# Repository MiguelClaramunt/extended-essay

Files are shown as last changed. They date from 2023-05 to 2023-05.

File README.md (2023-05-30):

# USB-C Adapters: Design improvement using a 3D printer

### **Status: Work in progress**

HDMI | Ethernet | USB-A + SD
:---:|:--------:|:----------:
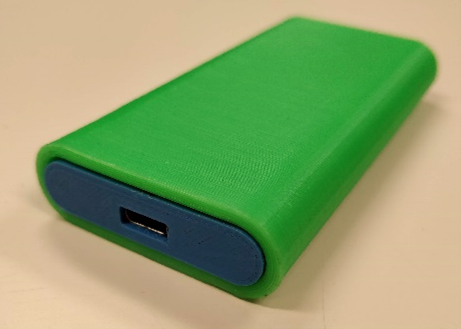
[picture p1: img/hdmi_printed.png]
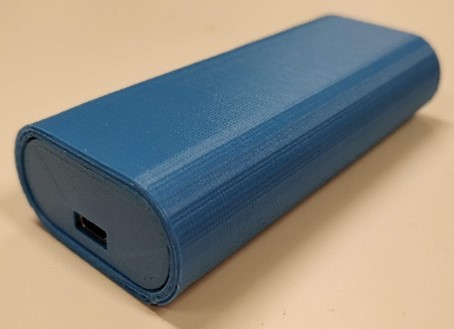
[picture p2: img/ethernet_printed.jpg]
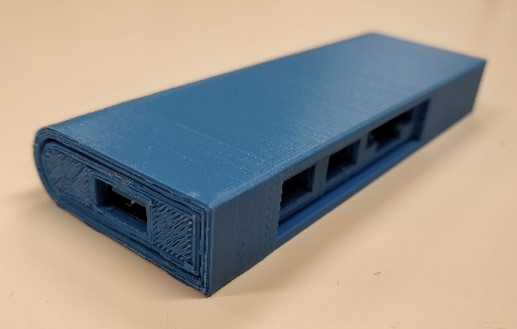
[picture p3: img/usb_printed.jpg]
 |  | 
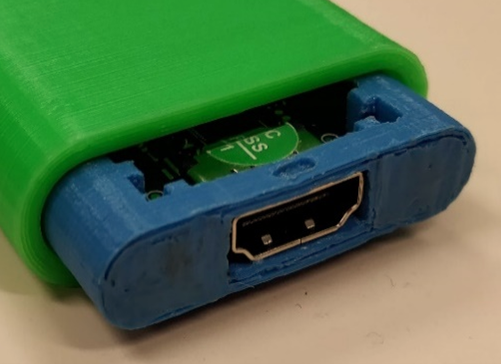
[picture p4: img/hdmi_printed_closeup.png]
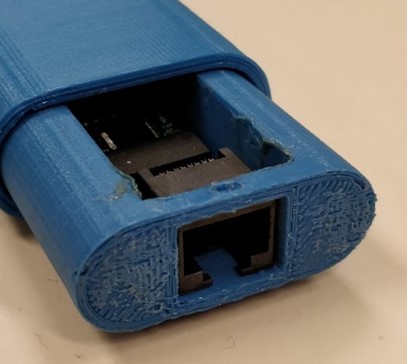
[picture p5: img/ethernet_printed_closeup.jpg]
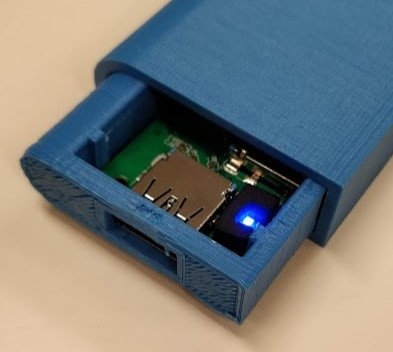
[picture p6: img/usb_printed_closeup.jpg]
 |  | 

## Research Question

> _"How can we improve the design of USB-C adapters to increase their durability and versatility?"_

<!-- ## Motivation -->

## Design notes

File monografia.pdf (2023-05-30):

# ADAPTADORES USB-C:

# MEJORA DEL DISEÑO UTILIZANDO

# UNA IMPRESORA 3D

## ¿Cómo podemos mejorar el diseño de los

## adaptadores de tipo USB-C para aumentar su

## durabilidad y versatilidad?

## Miguel Ricardo Claramunt Argote

Valencia, 21 de febrero de 2019

## Asignatura: TECNOLOGÍA DEL DISEÑO

Cómputo de palabras: 3949

## ÍNDICE

1. Introducción | 2
1.1 Introducción | 2
1.2 Pregunta de investigación | 3
1.3 Contexto | 4
1.4 Análisis de mercado | 6
1.5 Diseño | 7
1.6 Oportunidad de diseño | 9
1.7 Esquema general del proceso de producción | 11
2. Procedimiento | 11
2.1 Preparación del adaptador HDMI | 12
2.2 Preparación del adaptador Ethernet | 20
2.3 Preparación del adaptador USB/SD | 24
3. Conclusión | 28
4. Evaluación | 30
5. Bibliografía | 33

### 1. INTRODUCCIÓN (1467 palabras)

1.1.Introducción

El estándar USB-C es un nuevo tipo de

especificación de conexión que promete una

conexión físicamente reversible además de una

mayor tasa de transferencia de datos y potencia

de carga.

Con la implementación de este sistema, el

número de dispositivos que tienen este estándar ha aumentado considerablemente

desde su lanzamiento, con una previsión del 50% de smartphones y 93% de portátiles a

nivel mundial para el año 2020 (USB Implementers Forum, 2016). Aun así, para 2020

seguirá habiendo una gran lista de dispositivos con estándares anteriores (micro-USB,

VGA, etc.) por lo que la transición durará algunos años más.

En estos años de transición, existen situaciones en las que es necesario el uso de

adaptadores o dongles, como forma sustituir el estándar gradualmente. El problema que

hemos encontrado en su diseño es que suelen tener cables muy cortos y frágiles.

Además, el diseño de estos dispositivos, suele ser de una pieza, provocando que sean

irreparables, y con su uso diario haya que reemplazarlos en un corto período de tiempo.

Figura 1: Cable USB-C macho.

Fuente: Wikimedia Commons.

1.2.Pregunta de investigación

A partir de lo ya mencionado se nos ocurrió la siguiente pregunta de investigación:

“¿Cómo podemos mejorar el diseño de los adaptadores de tipo USB-C para aumentar

su durabilidad y versatilidad?”

Para responder esta pregunta diseñaremos un nuevo adaptador a partir de uno

ya comercializado, al que le diseñaremos una carcasa e intentaremos cambiar el tipo de

conexión que tiene (de USB-C macho a USB-C hembra) para hacerlo más duradero.

La carcasa la diseñaremos mediante el programa SketchUp y la imprimiremos con

una impresora 3D Prusa i3. Esta, mediante la extrusión de un filamento fundido por

capas, permite construir infinidad de modelos en cuestión de horas. El filamento que

utiliza, PLA (ácido poliláctico) es un polímero de origen orgánico, biodegradable y

reciclable, provocando que su impacto ambiental sea mínimo.

Gracias a que las impresoras 3D se han vuelto más populares y accesibles es

posible llevar a cabo proyectos como estos de forma sencilla, sin la necesidad de una

gran infraestructura.

Esta monografía se engloba dentro de la asignatura de Tecnología del Diseño, por

lo que nos centraremos en el diseño de las carcasas. Aun así, intentaremos abarcar un

poco del área de la electrónica, aunque no sea nuestro objetivo principal.

1.3.Contexto

El USB (USB-A) es un estándar cuyo diseño fue

publicado en 1996 con el fin de unificar la larga lista de

periféricos que había disponible, ofreciendo mayores

tasas de transferencia de datos, conexión en caliente

(sin tener que apagar el dispositivo), etc.

El nuevo estándar USB-C intenta solucionar los

problemas que tienen los demás estándares. Esto lo hace mediante la creación de un

puerto único, más pequeño (aproximadamente un 60% respecto al USB-A), mayores

tasas de carga y transferencia de datos. Además, su diseño permite que se pueda utilizar

de forma reversible, eliminando errores al conectarlo. Por lo tanto, se convierte en un

conector muy versátil, pudiendo colocarlo en la mayoría de aparatos electrónicos.

Para comenzar a mejorar el diseño de los adaptadores, escogimos diferentes

modelos para poner en práctica la versatilidad de este estándar, ya que puede transmitir

información a través de un gran número de protocolos: ethernet, video, audio, datos, etc.

De los protocolos mencionados anteriormente elegimos el de datos, vídeo y

ethernet. Realizamos una búsqueda en Amazon para comprar los modelos más afines a

este proyecto, que fueron los siguientes:

Figura 2: Cable USB-A macho.

Fuente: Wikimedia Commons.

Figura 3: Adaptador USB/SD

(AUKEY Hub USB 3.0, SD y

Micro SD)

Figura 4: Adaptador Ethernet

AUKEY.

Figura | 5: | Adaptador | HDMI

UGREEN.

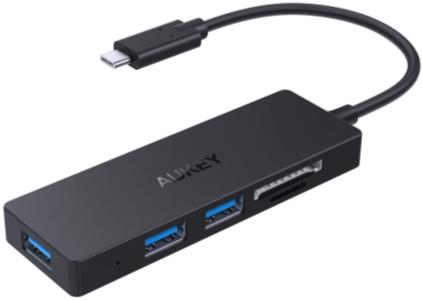
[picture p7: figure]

Fuente: Amazon. | Fuente: Amazon. | Fuente: Amazon.

Estos adaptadores constan de los siguientes componentes:

- Una placa base, que es la que se encarga de procesar la información proveniente

de un dispositivo principal (por ejemplo, la señal de vídeo de un ordenador) y

transmitirla al dispositivo secundario (un televisor).

- Un cable USB-C macho, que se conectaría al dispositivo principal, facilitando la

conexión entre ambos dispositivos (principal y secundario).

- Una carcasa, que contiene la placa base y sus circuitos internos, protegiéndola

del exterior.

Figura 6: Esquema de elementos de un adaptador.

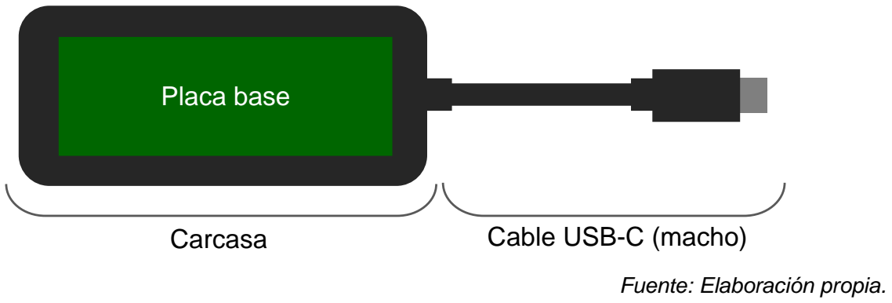
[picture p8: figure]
Fuente: Elaboración propia.; Carcasa; Cable USB-C (macho); Placa base

1.4.Análisis de mercado

Como hemos mencionado, el estándar USB-C es muy versátil, por lo que los

fabricantes se han aprovechado de ello para desarrollar una gran serie de productos que

se adapten a las necesidades de los compradores.

La mayoría de estos productos suelen conectarse directamente al USB-C del

dispositivo y mimetizarse con el diseño de este (véase Figura 7). Además, permiten una

gran serie de conexiones a una alta velocidad con el uso de un conector (véase Figura

8). Todos ellos intentan darle más esperanza de vida al estándar antes de que quede

obsoleto mientras los compradores pueden adaptarse paulatinamente a la

implementación completa del estándar.

Figura 7: Hub USB-C ENKLEN. | Figura 8: Hub USB-C 5 Lenovo.

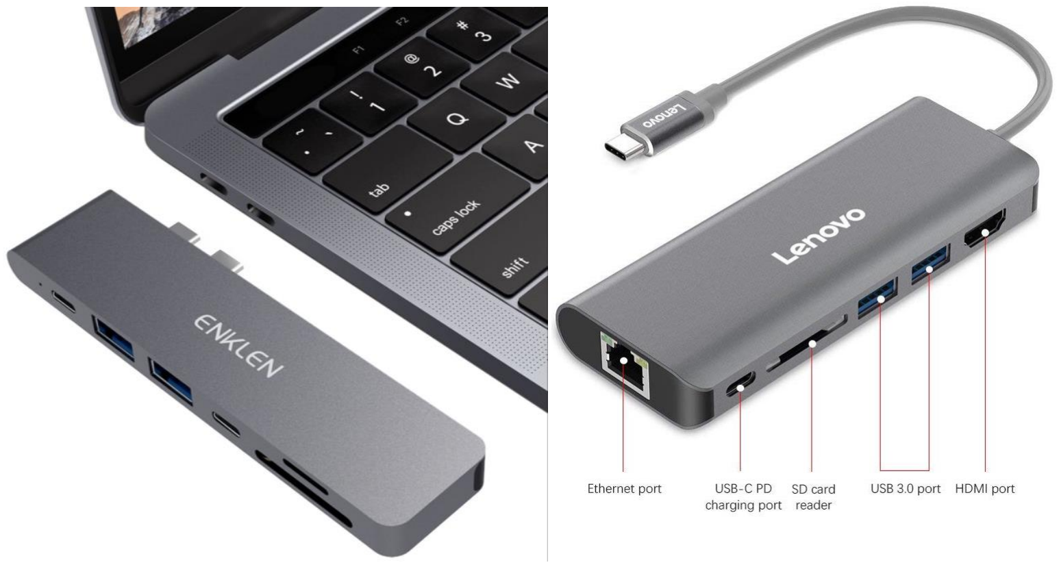
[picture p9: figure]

Fuente: Amazon. | Fuente: Amazon.

1.5.Diseño

Nos inspiramos en el diseño que tienen los

adaptadores de Apple, ya que su diseño es muy

similar en todos los tipos de adaptadores que tienen

en venta: un ortoedro con semicilindros en dos de sus

lados opuestos.

Nuestra propuesta de diseño es la siguiente: utilizar la placa base existente, a la

que retiraremos el cable USB-C macho y soldaremos una placa USB-C hembra,

finalmente, diseñaremos una carcasa que contendría a la placa base y al USB-C hembra.

El cambio de conector USB-C (macho por hembra) nos permite utilizar un cable

USB-C macho-macho. Así podríamos quitar el cable para que el adaptador ocupe

menos, reemplazarlo por uno nuevo si este se rompe por el uso o utilizar un cable con

una longitud diferente si la situación lo requiere.

Figura | 9: | Ortoedro | con | dos

semicilindros en sus lados opuestos.

Fuente: Elaboración propia.

Figura 10: Adaptador

USB-C a SD.

Figura 11: Adaptador

USB-C a USB-A.

Figura 12: Adaptador

USB-C a HDMI y USB-A.

Figura 13: Adaptador

USB-C a Ethernet.

Fuente: Apple. | Fuente: Apple. | Fuente: Apple. | Fuente: Apple.

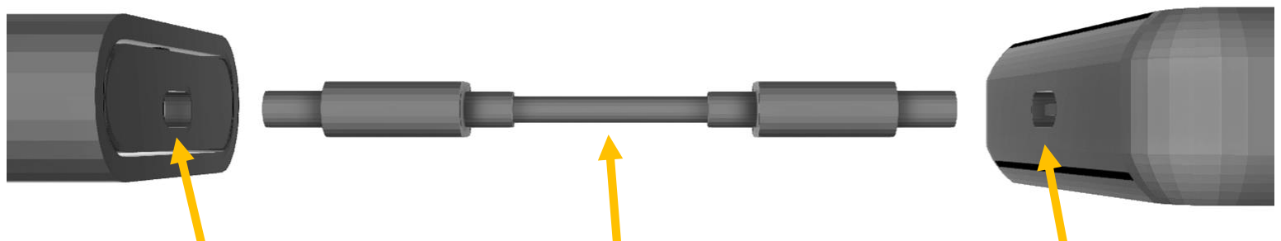
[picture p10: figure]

La carcasa consistiría en un cuerpo y una tapa, permitiendo proteger los

componentes internos de amenazas externas (golpes, caídas, etc.) aunque sin dificultar

el acceso a los mismos componentes. Por ende, el proceso de reparación o modificación

sería mucho más sencillo. El diseño de la carcasa sería idéntico al de la estructura

externa del cuerpo, pero eliminando las dos paredes que corresponden al lugar donde

están colocados el puerto del adaptador y el cable USB-C hembra. Así, para cerrar el

adaptador solamente habría que deslizar el cuerpo dentro de la tapa hasta alinearla con

el sistema de cierre.

El sistema de cierre entre la tapa y el cuerpo constaría de un saliente en el interior

de la tapa y un agujero en el cuerpo. Entonces, al deslizar el cuerpo dentro de la tapa, el

saliente y el agujero encajarán y las dos partes quedarían bloqueadas. Para expulsar el

cuerpo solamente haría falta hacer un poco de presión en él.

Figura 14: Funcionamiento de los adaptadores a partir del nuevo diseño.

Fuente: Elaboración propia.

Adaptador USB-C a
HDMI, Ethernet,
USB/SD, etc.
Cable USB-C macho-macho | Dispositivo principal (disco duro, ordenador, etc.)

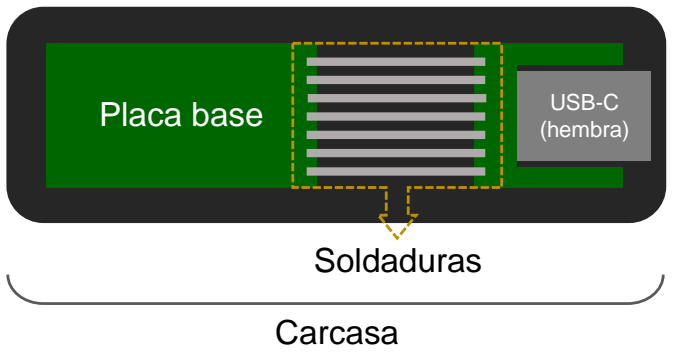
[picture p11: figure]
Placa base; USB-C; (hembra); Carcasa; Soldaduras

1.6.Oportunidad de diseño

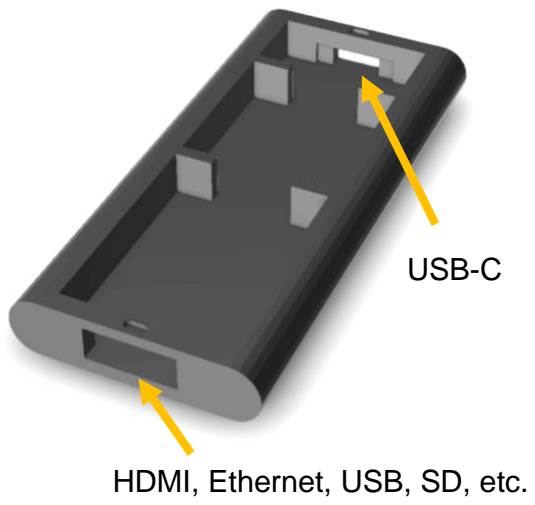
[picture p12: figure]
HDMI, Ethernet, USB, SD, etc.; USB-C

Mediante este cambio de diseño en la carcasa y componentes internos,

mejoraríamos la resistencia y la versatilidad del adaptador por las siguientes razones:

Resistencia:

- El cable, uno de los componentes más frágiles, se pordía reemplazar fácilmente,

evitando desmontarlo y soldarlo para sustituirlo.

Figura 15: Propuesta de diseño (cuerpo y circuitería). | Figura 16: Propuesta de diseño (tapa).
Fuente: Elaboración propia. | Fuente: Elaboración propia.
Figura 17: Propuesta de diseño (sistema de cierre). | Figura 18: Propuesta de diseño (cuerpo).

c

Fuente: Elaboración propia. | Fuente: Elaboración propia.
Agujero | Saliente

- La carcasa, al poder abrirse, permitiría reparar los componentes internos que se

hayan estropeado o incluso actualizarse si la tecnología evoluciona, alargando la

vida útil del adaptador considerablemente.

Versatilidad:

- Ocuparía menor espacio, ya que el módulo y el cable se podrían colocar por

separado.

- Se podrían conectar cables de diferentes longitudes según la situación,

permitiendo su uso en situaciones más diversas.

Otros factores que se mejorarían del diseño serían los siguientes:

- La sostenibilidad ambiental, mediante el uso de PLA (ácido poliláctico), un

polímero biodegradable y reciclable. Al ser de origen orgánico, su impacto

ambiental se reduce drásticamente.

- La personalización del diseño, pudiendo realizarse fácilmente mediante

herramientas de diseño en 3D permite que cada persona pueda adaptar la

carcasa a sus necesidades.

- Una mayor accesibilidad al público, que puede imprimir sus diseños de carcasas

mediante una impresora 3D, llegando hasta a países en vías de desarrollo, donde

la infraestructura tecnológica no permite tal tipo de proyectos.

1.7.Esquema general del proceso de producción

Los pasos que realizaremos en los tres adaptadores fueron los siguientes:

1. Preparación de la placa base.

1.1.Desensamblaje de la carcasa original.

1.2.Eliminación del puerto USB-C macho.

2. Preparación del conector USB-C hembra.

2.1.Diseño del esquema de conexiones.

2.2.Preparación y soldadura de los cables del adaptador al conector USB-C hembra.

3. Diseño e impresión de las carcasas.

3.1.Toma de medidas y diseño del prototipo.

3.2.Impresión del prototipo.

3.3.Diseño final.

3.4.Impresión del diseño final.

4. Comprobación y mejora de errores.

### 2. PROCEDIMIENTO (1561 palabras)

El procedimiento que vamos a utilizar en los tres adaptadores va a ser

prácticamente el mismo, por esta razón, comenzaremos con el adaptador más complejo,

describiendo con mucha precisión todos los pasos e inconvenientes del proceso.

Seguidamente, con los siguientes adaptadores explicaremos el procedimiento de

manera más resumida, aunque haciendo hincapié en los problemas encontrados,

evitando redundancias y haciendo más amena la lectura.

2.1.Preparación del adaptador HDMI.

1. Preparación de la placa base.

1.1.Desensamblaje de la carcasa original.

La primera parte del proceso de preparación del adaptador HDMI consistió en

retirar la placa base de la carcasa original (véase Figura 5).

Al tratarse de una carcasa de aluminio, para retirarla tuvimos que limarla hasta

llegar a la placa. Este paso hay que hacerlo con precaución, ya que las limaduras

metálicas pueden causar algún tipo de cortocircuito o fallo de la placa. En el proceso

de doblar la carcasa para extraer la placa hay que tener cierto cuidado para no

golpear y despegar ningún chip soldado a la placa base. La carcasa, al tener poca

superficie, ser muy dura y tener poco espacio de maniobra provocó que aplicáramos

mucha fuerza en ella, resultando que golpeáramos con un alicate un chip y

dejáramos la placa inutilizable, por lo que tuvimos que sustituirla. Por esa razón,

decidimos elegir un modelo diferente, este en vez de tener una salida HDMI macho

decidimos que fuera hembra. De esta forma se adaptaría más a nuestra lista de

características que queremos mejorar.

A la hora de retirar la carcasa el proceso fue más sencillo debido a que la

forma era diferente y el material era más dúctil, por lo que no hubo ninguna

complicación.

1.2.Eliminación del puerto USB-C macho.

Para este proceso cogimos el cable USB-C macho, lo cortamos con unas

tijeras, retiramos el apantallado metálico y plástico con unas tijeras. De esta forma

teníamos todos los cables disponibles para soldarlos.

2. Preparación del conector USB-C hembra.

2.1.Diseño del esquema de conexiones.

Para realizar el esquema de las conexiones utilizamos el cable USB-C macho

cortado anteriormente, pelamos los cables y conectamos el cable a la placa USB-C

hembra. De esta forma, con la ayuda de un multímetro podemos asignar un cable

con una pista de la placa.

Figura 19: Placa USB-C hembra con esquema de pistas. | Figura 20: Esquema de pistas y cables.

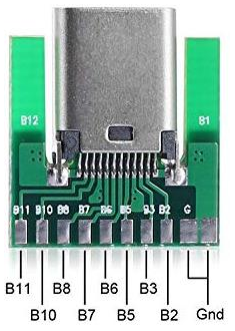
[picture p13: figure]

Pista | Cable | Pista | Cable
Gnd | Negro-Rojo | Gnd | Negro-Rojo
B2 | Azul | A2 | Marrón
B3 | Amarrillo | A3 | Blanco
B5 | Azul | Vcc | -
B6 | Verde | A5 | Amarillo
B7 | Blanco | A6 | -
B8 | Morado | A7 | -
B10 | Blanco | A8 | Rosa
B11 | Rojo | A10 | Naranja
| | A11 | Morado

Cada par de pistas coloreadas representa dos cables trenzados.

Fuente: Amazon. | Fuente: Elaboración propia.

2.2.Preparación y soldadura de los cables del adaptador al conector USB-C

hembra.

Una vez preparados los cables y retirado el apantallado procedimos a pelarlos,

de esta forma podíamos soldarlos adecuadamente. A continuación, decapamos y

estañamos los cables.

Hay que tener especial cuidado al pelar los cables, ya que estos son muy finos

y se rompen fácilmente con el uso de herramientas como un pelacables. Por esta

razón, los retiramos con mucho cuidado y la ayuda de una cuchilla o con las uñas

para retirar el aislante.

Con los cables ya estañados y el esquema de las conexiones listo, procedimos

a soldar cada cable en su conexión. Para ello utilizamos un soldador de punta fina,

estaño y decapante.

3. Diseño de la carcasa.

3.1.Toma de medidas y diseño del prototipo.

Con un pie de rey realizamos las medidas pertinentes de la placa base y las

apuntamos para pasarlas al programa de diseño 3D. Procedimos a diseñar un

prototipo “base”, en el que probaremos la estructura de la carcasa y a partir de ahí

iremos añadiendo mejoras estéticas.

Con el programa SketchUp dibujamos la plantilla del espacio que ocuparía la

placa base y a partir de ahí diseñamos una carcasa sin ningún tipo de decoración

estética para comprobar su estructura y si los espacios para los puertos estaban bien

colocados.

3.2.Impresión del prototipo.

Después de haber diseñado el prototipo procedimos a imprimirlo con la

impresora 3D, para ello exportamos el diseño de SketchUp en formato stl. No

encontramos ningún problema significativo, por lo que continuamos con el diseño del

prototipo final.

3.3.Diseño final.

A partir del diseño del prototipo “base” que imprimimos anteriormente,

procedimos a añadir las características mencionadas en el diseño final. Para ello,

añadimos las dos caras curvas y ajustamos la altura para que fuese simétrico.

Finalmente, diseñamos la tapa y añadimos el sistema de cierre en las dos partes.

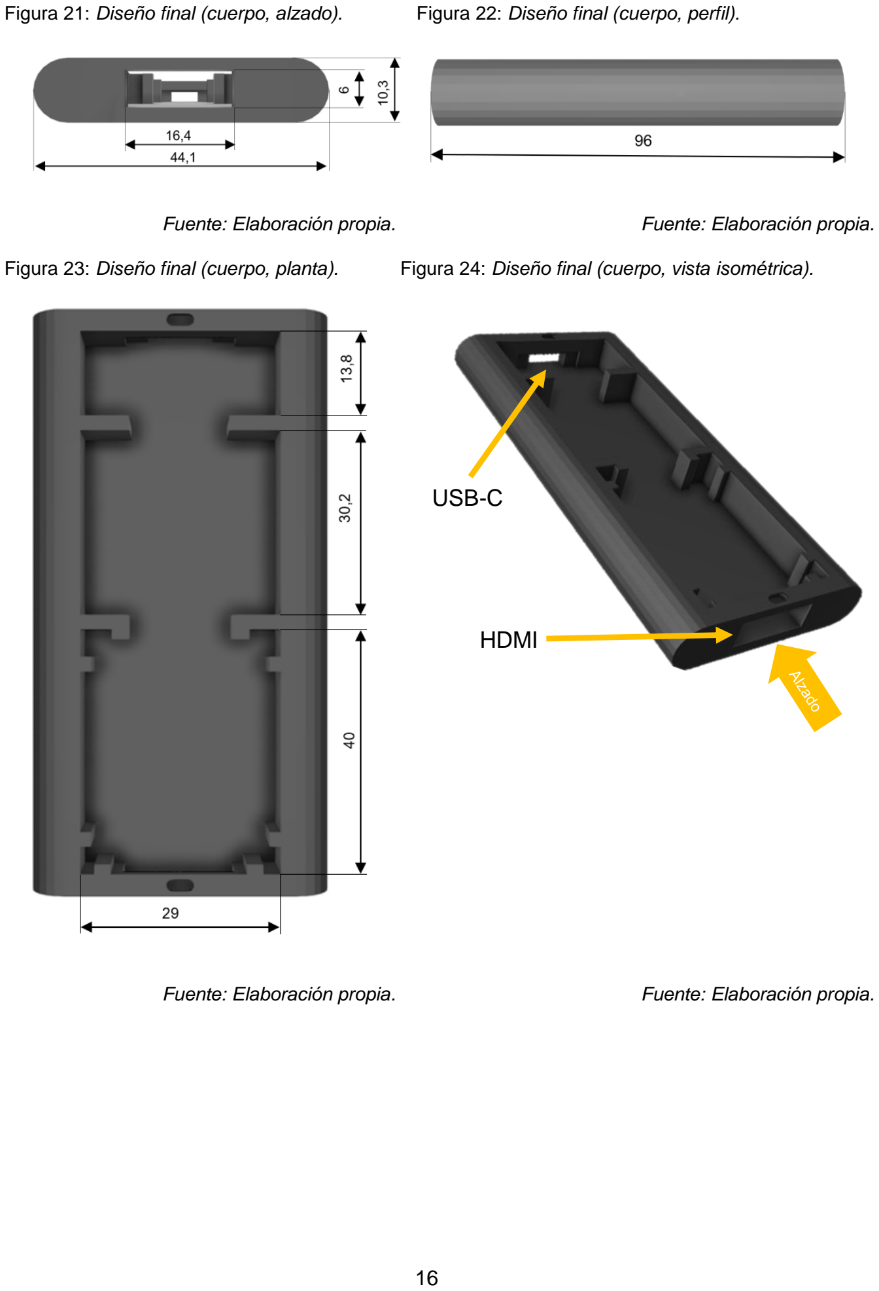
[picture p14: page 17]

Figura 21: Diseño final (cuerpo, alzado). | Figura 22: Diseño final (cuerpo, perfil).
Fuente: Elaboración propia. | Fuente: Elaboración propia.
Figura 23: Diseño final (cuerpo, planta). | Figura 24: Diseño final (cuerpo, vista isométrica).
Fuente: Elaboración propia. | Fuente: Elaboración propia.

USB-C

HDMI

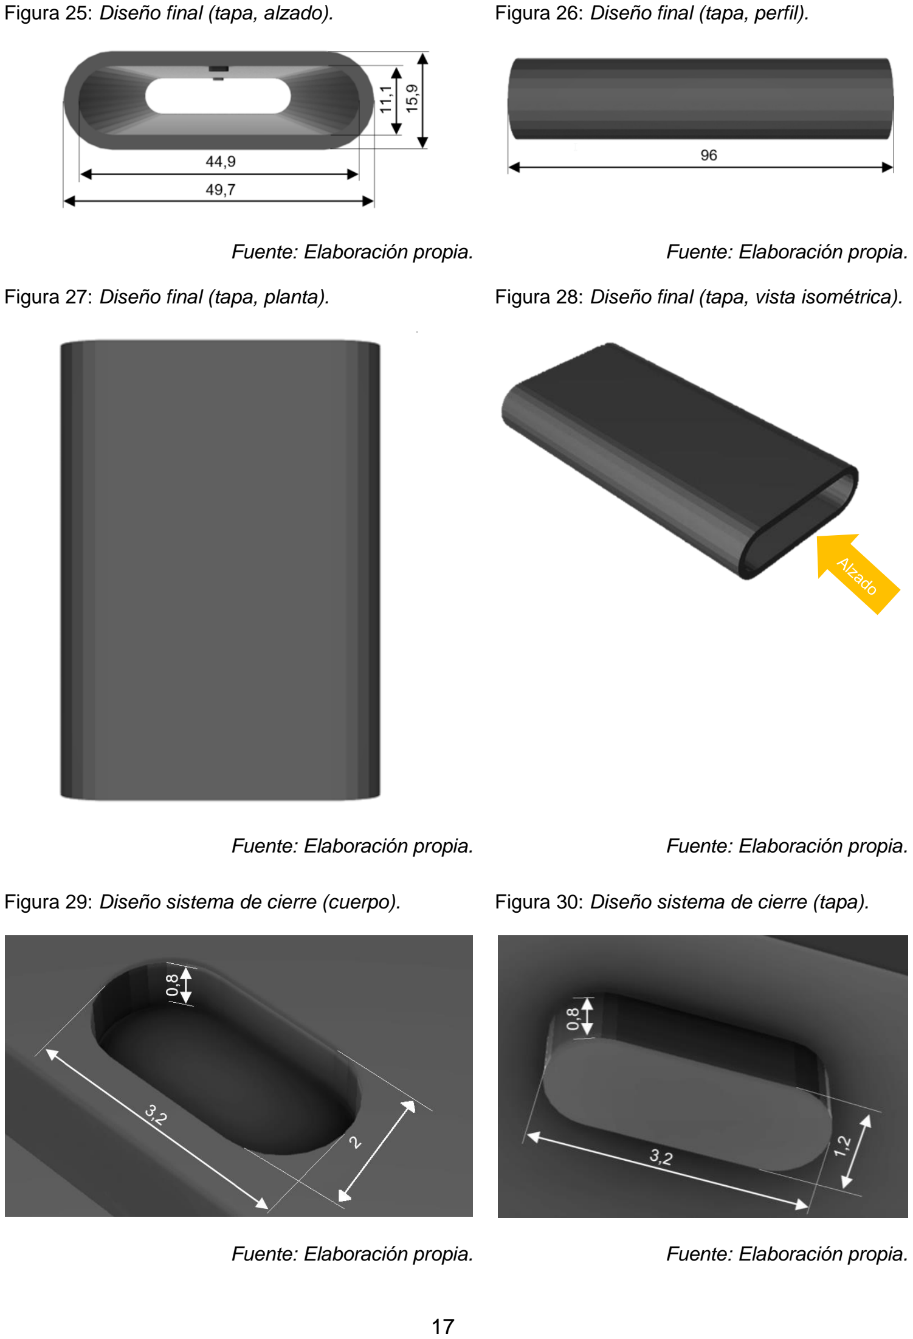
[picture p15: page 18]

Figura 25: Diseño final (tapa, alzado). | Figura 26: Diseño final (tapa, perfil).
Fuente: Elaboración propia. | Fuente: Elaboración propia.
Figura 27: Diseño final (tapa, planta). | Figura 28: Diseño final (tapa, vista isométrica).

X

Fuente: Elaboración propia. | Fuente: Elaboración propia.
Figura 29: Diseño sistema de cierre (cuerpo). | Figura 30: Diseño sistema de cierre (tapa).
Fuente: Elaboración propia. | Fuente: Elaboración propia.

3.4.Impresión del diseño final.

Ya exportado el diseño final a formato stl procedimos a imprimirlo con la

impresora 3D. De esta forma lo imprimimos horizontalmente, ya que tiene más

estabilidad y funcionó bien en la impresión del prototipo. Al finalizar la impresión

observamos que había algunos problemas en la impresión de las zonas curvas, ya

que estas no tienen ningún tipo de estructura a la que puedan adherirse y ocurren

desperfectos estéticos que provocan que no se pueda insertar correctamente el

cuerpo dentro de la tapa.

Después de ver los buenos

resultados de la impresión en vertical

de la tapa probamos a imprimir el

cuerpo de la misma manera. Hubieron

algunos intentos fallidos donde el

cuerpo se imprimía mal porque no se

sujetaba bien a la base de la impresora,

por lo que procedimos a darle mayor

Figura 31: Proceso de impresión en horizontal. | Figura 32: Resultado de la impresión.

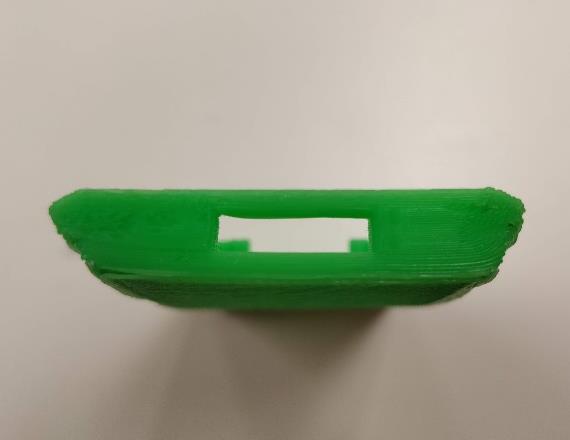
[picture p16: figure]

Fuente: Elaboración propia. | Fuente: Elaboración propia.

Figura 33: Resultados de la impresión en vertical.

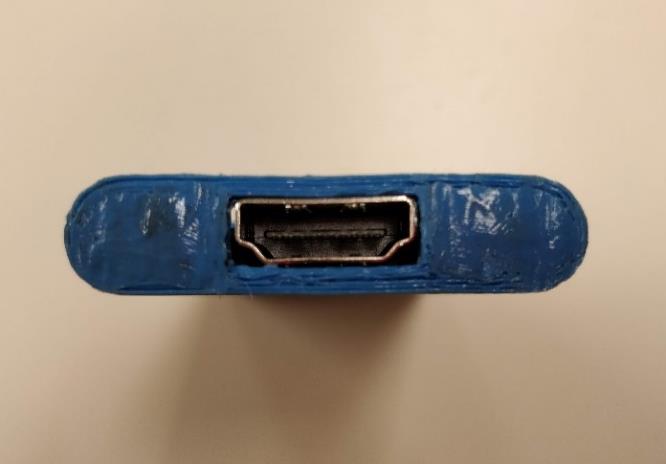
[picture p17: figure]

Fuente: Elaboración propia.

espesor a la estructura de sujeción de la base para que no oscilase. Finalmente,

conseguimos imprimir el cuerpo del adaptador satisfactoriamente y sin ninguna

anomalía estética.

Habiendo encontrado la forma de imprimir correctamente las piezas

procedimos a ensamblar los componentes electrónicos del adaptador en su carcasa.

4. Comprobación y mejora de errores.

En el proceso de ensamblaje encontramos los siguientes errores:

- El conector USB-C hembra no sobresalía lo suficiente para hacer una buena

conexión.

- La placa USB-C hembra no tenía ninguna forma de sujeción, por lo que al insertar

un cable esta se introducía para el interior de la carcasa.

Para ello, los arreglamos de la siguiente manera:

- Para que conectase correctamente el USB-C hembra procedimos a reducir el

espesor de la pared donde se conecta el adaptador. Asímismo, se podría conectar

y estaría un poco mejor sujeto que en el diseño anterior.

- Para sujetar la placa USB-C hembra decidimos alargar un poco más las paredes

que sujetan la placa base y colocarlo de forma que sujeten por la parte de las

soldaduras. Así al conectar el cable USB-C macho no debería moverse hacia

adentro.

2.2.Preparación del adaptador Ethernet

1. Preparación de la placa base.

1.1.Desensamblaje de la carcasa original y 1.2. Eliminación del puerto USB-C macho.

La carcasa original al ser de plástico (véase Figura 4), el proceso de

desensamblaje fue muy fácil, utilizando una cuchilla y unos alicates eliminamos la

estructura interior con cuidado de no golpear ningún chip o componente interno de

la placa para asegurar su correcto funcionamiento. A continuación, cortamos el cable

con una cuchilla o unos alicates y retiramos el apantallado.

2. Preparación del conector USB-C hembra.

2.1.Diseño del esquema de conexiones y 2.2. Preparación y soldadura de los cables

del adaptador al conector USB-C hembra.

Pelamos los cables del conector USB-C macho, conectamos el conector a la

placa y mediante un polímetro comprobamos la correspondencia entre cable y pista.

Figura 34: Placa USB-C hembra con esquema de pistas. | Figura 35: Esquema de pistas y cables.

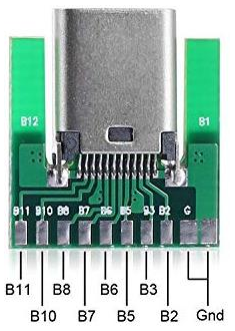
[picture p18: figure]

Pista | Cable | Pista | Cable
Gnd | Negro | Gnd | Tierra
B2 | - | A2 | Azul
B3 | - | A3 | Negro
B5 | Azul | Vcc | Rosa
B6 | - | A5 | Naranja
B7 | - | A6 | Verde
B8 | - | A7 | Blanco
B10 | Blanco | A8 | -
B11 | Rojo | A10 | -
| | A11 | -
Cada | par | de | pistas | coloreadas
representa dos cables trenzados.
Fuente: Amazon. | Fuente: Elaboración propia.

Procedemos a pelar los cables del adaptador, decaparlos y estañarlos para

soldarlos a la placa USB-C hembra con ayuda de un soldador fino.

3. Diseño e impresión de las carcasas.

3.1.Toma de medidas y diseño del prototipo y 3.2. Impresión del prototipo

Tomamos las medidas de la placa base con un con un pie de rey y diseñamos

un prototipo a partir de las medidas obtenidas, exportamos e imprimimos el modelo

para comprobar la estructura y correcta colocación de los puertos. Todas estas

comprobaciones resultaron satisfactorias, por lo que no hizo falta realizar ninguna

modificación.

3.3.Diseño final y 3.4. Impresión del diseño final.

A partir del prototipo, aplicamos las características de diseño e intentamos

solucionar los errores encontrados en procesos de producción de los adaptadores

anteriores para malgastar la menor cantidad de recursos posible. Finalmente,

imprimimos la carcasa y la tapa en posición perpendicular a la zona de impresión y lo

imprimimos con una pequeña base más gruesa de lo normal para evitar que oscile.

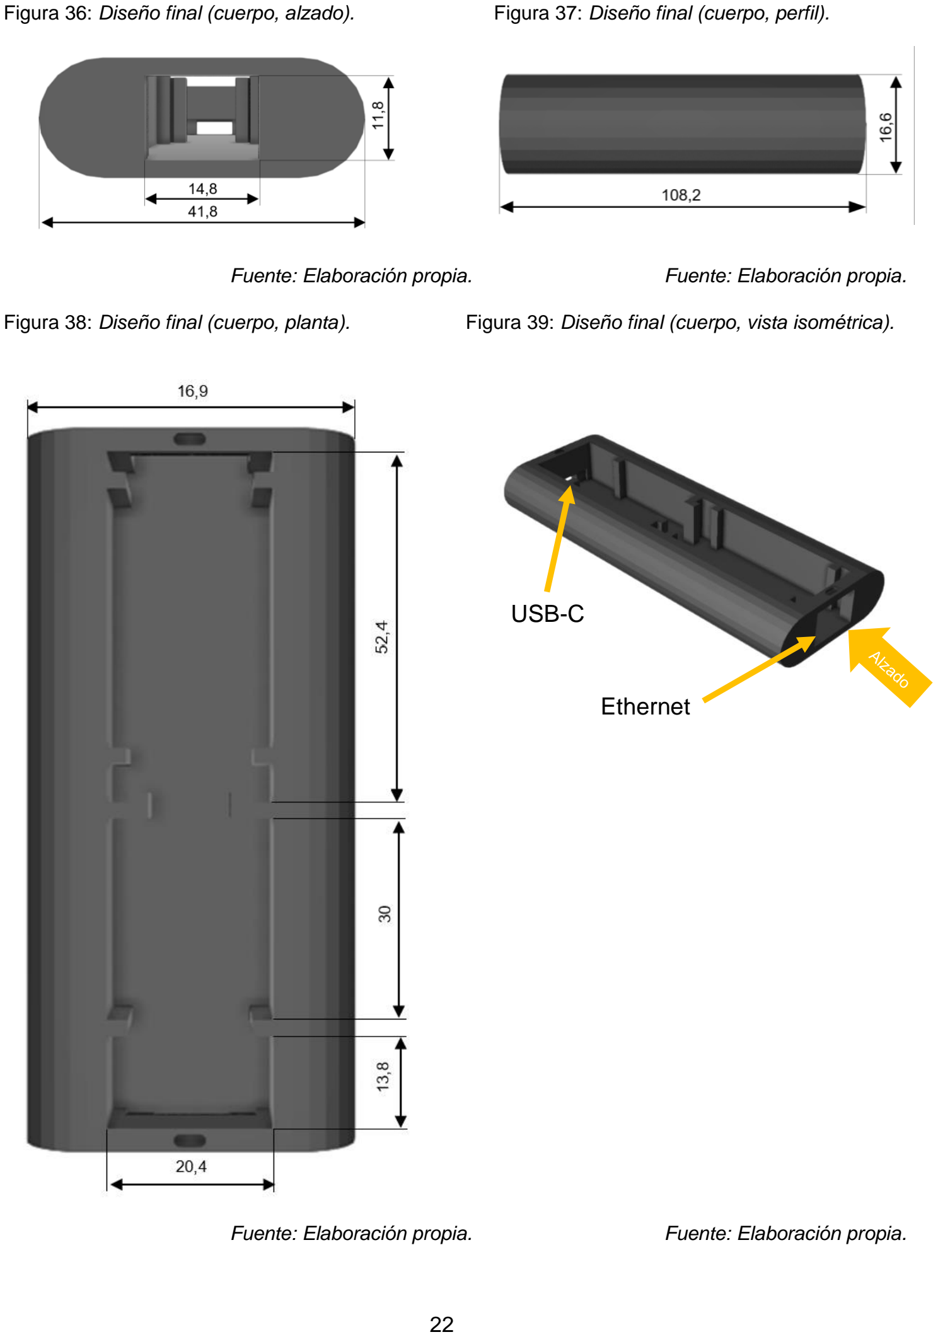
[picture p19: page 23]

Figura 36: Diseño final (cuerpo, alzado). | Figura 37: Diseño final (cuerpo, perfil).
Fuente: Elaboración propia. | Fuente: Elaboración propia.
Figura 38: Diseño final (cuerpo, planta). | Figura 39: Diseño final (cuerpo, vista isométrica).
Fuente: Elaboración propia. | Fuente: Elaboración propia.

USB-C

Ethernet

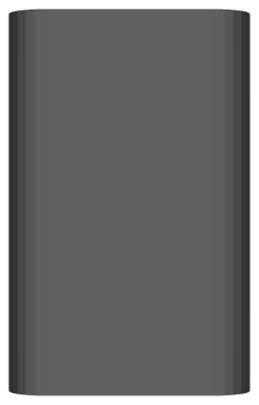
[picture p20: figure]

4. Comprobación y mejora de errores.

Habiendo tenido en cuenta las pequeñas modificaciones realizadas a la hora de

diseñar el modelo final, hemos evitado imprimir modelos innecesariamente. Por último,

colocando los componentes internos y la tapa no se encuentra ningún tipo de defecto

estético o de funcionamiento.

Figura 40: Diseño final (tapa, alzado). | Figura 41: Diseño final (tapa, perfil).
Fuente: Elaboración propia. | Fuente: Elaboración propia.
Figura 42: Diseño final (tapa, planta). | Figura 43: Diseño final (tapa, vista isométrica).
Fuente: Elaboración propia. | Fuente: Elaboración propia.

2.3.Preparación del adaptador USB/SD

1. Preparación de la placa base.

1.1.Desensamblaje de la carcasa original y 1.2. Eliminación del puerto USB-C macho.

Con unos alicates y la ayuda de una cuchilla retiramos la carcasa de plástico

(véase Figura 3), teniendo especial cuidado en no dañar con las herramientas o

agentes externos la placa base. Con unas tijeras cortamos el cable y retiramos el

apantallado que tienen los cables para trabajar cómodamente con ellos.

2. Preparación del conector USB-C hembra.

2.1.Diseño del esquema de conexiones y 2.2. Preparación y soldadura de los cables

del adaptador al conector USB-C hembra.

Con el puerto USB-C macho cortado anteriormente, conectamos el USB-C

macho a la placa USB-C y con un polímetro asignamos cada cable con una pista de

la placa.

Figura 44: Placa USB-C hembra con esquema de pistas. | Figura 45: Esquema de pistas y cables.

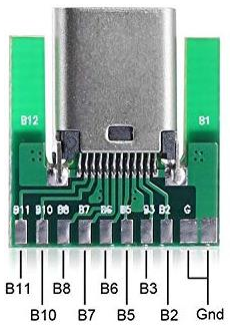
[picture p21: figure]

Pista | Cable | Pista | Cable
Gnd | Negro | Gnd | Tierra
B2 | - | A2 | Naranja
B3 | - | A3 | Lila
B5 | - | Vcc | Rojo
B6 | - | A5 | -
B7 | - | A6 | Verde
B8 | - | A7 | Blanco
B10 | Azul | A8 | -
B11 | Amarillo | A10 | -
| | A11 | -
Cada | par | de | pistas | coloreadas
representa dos cables trenzados.
Fuente: Amazon. | Fuente: Elaboración propia.

Pelamos los cables, los decapamos y los soldamos con estaño y un soldador

fino. Después, los soldamos a la placa base con la ayuda de más estaño y decapante

si es necesario.

3. Diseño e impresión de las carcasas.

3.1.Toma de medidas y diseño del prototipo y 3.2. Impresión del prototipo.

Con un pie de rey tomamos las medidas y diseñamos un prototipo que

usaremos para comprobar si encajan correctamente los puertos además de la

estructura.

Después de imprimirlo, observamos que este diseño necesitaba algunas

mejoras ya que los puertos para tarjetas SD están muy cerca, provocando que el

plástico que haya entre ellos sea muy frágil, por lo que decidimos eliminarlo.

3.2.Diseño final y 3.3. Impresión del diseño final.

El diseño final de este modelo debía ser

diferente a los dos anteriores porque este

adaptador tiene en uno de sus lados más

puertos, por lo que, si se añade más grosor a

las paredes que contienen los semicilindros,

algunos tipos de cables USB puede que no se

inserten correctamente. Para ello, elegimos

tomar la decisión de dejar un único semicilindro a uno de los lados, concretamente

el que carece de puertos.

La tapa de este adaptador tendría que mantener la estética global de este, por

lo que tiene el mismo diseño que el cuerpo. Para evitar que la tapa también obstruya

Figura 46: Ortoedro con un semicilindro.

Fuente: Elaboración propia.

los puertos, decidimos hacer el espacio destinado para los puertos mucho más

grande.

Finalmente, imprimimos la tapa y el cuerpo de forma vertical, perpendicular a

la zona de impresión y con una base ancha para que no oscilase.

Figura 47: Diseño final (cuerpo, alzado). | Figura 48: Diseño final (cuerpo, perfil).

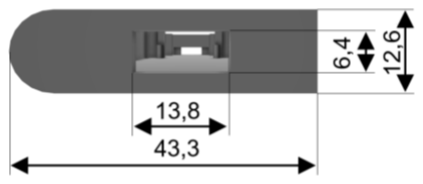
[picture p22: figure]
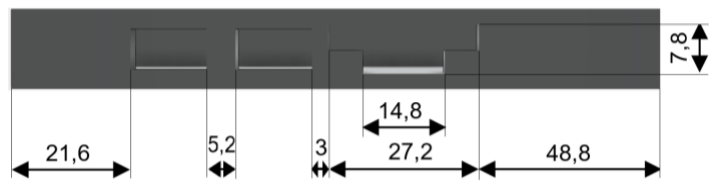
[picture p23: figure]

Fuente: Elaboración propia. | Fuente: Elaboración propia.
Figura 49: Diseño final (cuerpo, planta). | Figura 50: Diseño final (cuerpo, vista isométrica).

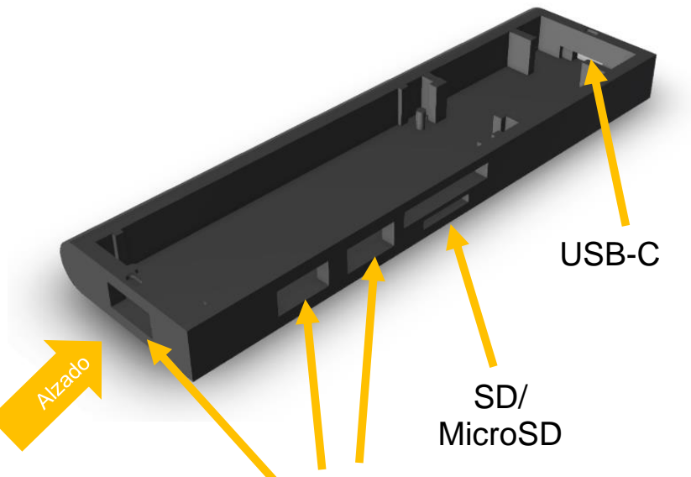
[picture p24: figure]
USB-C; SD/ MicroSD
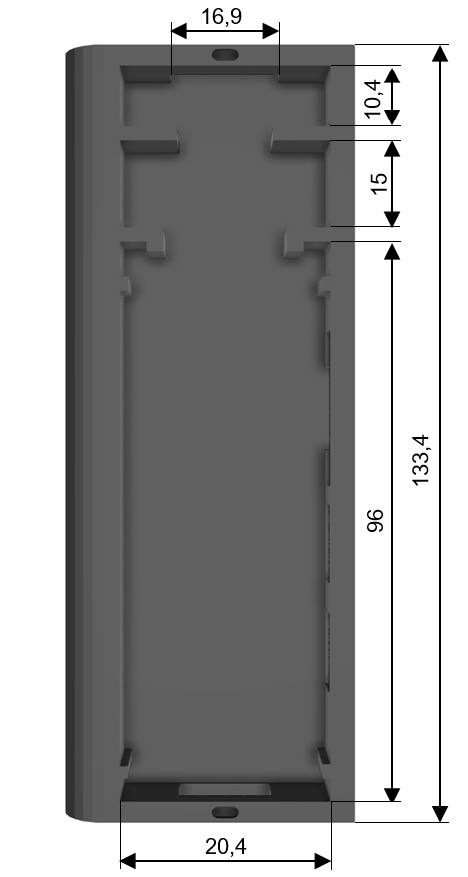
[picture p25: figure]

Fuente: Elaboración propia. | Fuente: Elaboración propia.

USB-A

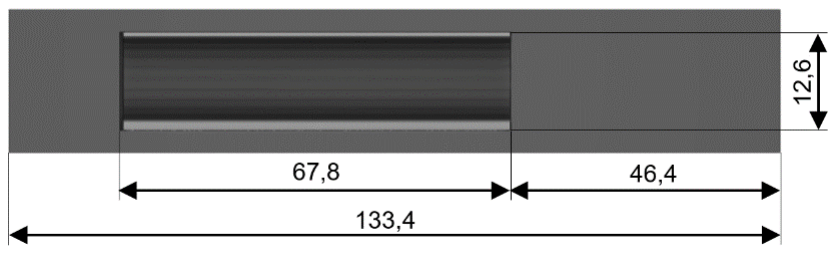
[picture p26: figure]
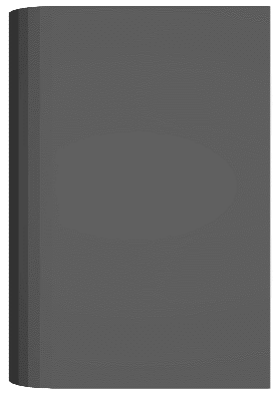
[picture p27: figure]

4. Comprobación y mejora de errores.

Finalmente, comprobamos que los puertos se podían insertar correctamente,

debido a las limitaciones mencionadas anteriormente, la tapa y el sistema de cierre

funcionaban adecuadamente y los puertos podían ser utilizados sin ningún tipo de

complicación.

Figura 51: Diseño final (tapa, alzado). | Figura 52: Diseño final (tapa, perfil).
Fuente: Elaboración propia. | Fuente: Elaboración propia.
Figura 53: Diseño final (tapa, planta). | Figura 54: Diseño final (tapa, vista isométrica).
Fuente: Elaboración propia. | Fuente: Elaboración propia.

### 3. CONCLUSIÓN (406 palabras)

“¿Cómo podemos mejorar el diseño de los adaptadores de tipo USB-C para aumentar

su durabilidad y versatilidad?”

Mediante este diseño hemos demostrado la versatilidad del estándar USB-C,

además, hemos creado desde cero un diseño de carcasas universal, modificable y

accesible a un mayor número de personas gracias al uso de impresoras 3D.

Figura 55: Adaptador USB-C a HDMI. | Figura 56: Adaptador USB-C a
| Ethernet.

Figura 57: Adaptador USB-C

a USB/SD.

Fuente: Elaboración propia. | Fuente: Elaboración propia. | Fuente: Elaboración propia.

Figura 58: Adaptador USB-C a

HDMI.

Figura 59: Adaptador USB-C a

Ethernet.

Figura 60: Adaptador USB-C a

USB/SD.

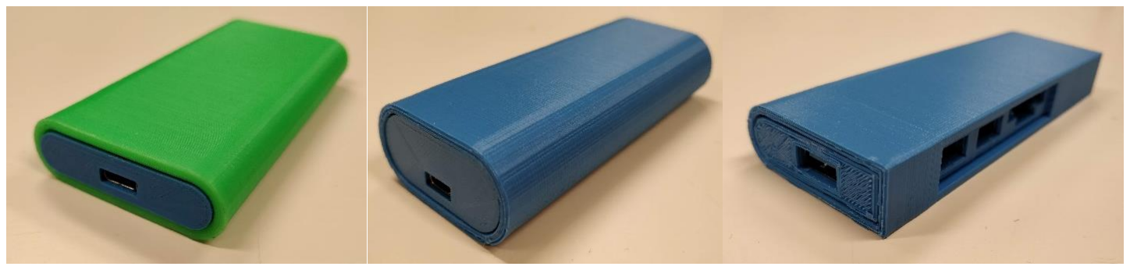
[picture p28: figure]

Fuente: Elaboración propia. | Fuente: Elaboración propia. | Fuente: Elaboración propia.

Aunque la electrónica de los tres dispositivos no haya funcionado adecuadamente

como se había presentado al principio (mediante el uso de un cable USB-C macho-macho), uno de ellos (el adaptador USB/SD) funciona adecuadamente con un cable

diferente, de USB-C a USB-A, por lo que llega a cumplir la mayoría de propuestas

mencionadas. El adaptador HDMI funciona, ya que recibe energía, aunque no existe

transferencia de información debido a las limitaciones del estándar USB-A. Por último, el

adaptador Ethernet podría llegar a funcionar con el estándar USB-A, pero se requeriría

de controladores o drivers especiales para hacerlo funcionar, cosa que el fabricante no

proporciona.

La razón de que haya funcionado con un cable diferente es que los dos

adaptadores (USB/SD y Ethernet) requieren solamente de una conexión USB-A para

funcionar, saltándose las limitaciones que tiene el estándar USB-C. Además, el estándar

USB-A no requiere de tantas protecciones como el USB-C, ya que este trabaja en un

voltaje y amperaje estándar (5 V/1,5 A), mientras que el USB-C trabaja con un abanico

más amplio (hasta 20 V/5 A). Por consiguiente, requiere de estas protecciones para evitar

sobrecargas de tensión en algunos dispositivos.

La falta de información sobre el estándar debido a su reciente implementación y

la falta de investigación o desarrollo por parte de terceros provocó que esta información

se descubriese en fases finales del proceso. Por tanto, no tuvimos mucho margen de

tiempo para aplicar las mejoras pertinentes. Por último, cabe mencionar que, aunque

hubiésemos tenido más tiempo, la falta de infraestructura del centro y la falta de

experiencia en el campo no nos hubiera permitido aplicar una solución válida o viable.

Concluyendo, a pesar de que la parte electrónica del adaptador no haya

funcionado correctamente, el diseño aplicado a la carcasa que se ha desarrollado podría

utilizarse en otros proyectos. El sistema de cierre también podría ser útil en situaciones donde se quiere esconder este sistema por razones estéticas y quedaría cerrado sin

ningún indicio de ello.

### 4. EVALUACIÓN (612 palabras)

Este producto se ha realizado con éxito en uno de los tres adaptadores con el uso

de un cable diferente debido a las limitaciones del estándar USB-C. Aun así, las carcasas

diseñadas para las placas base de los adaptadores cumplen satisfactoriamente la

mayoría de características propuestas en el apartado de diseño.

El procedimiento elegido para producir los adaptadores fue eficiente, ya que se

diseñaban las carcasas a partir de las placas, ya que estas últimas son más difíciles de

modificar. Al diseñar un primer prototipo base en vez de diseñar el modelo final pudimos

corregir los defectos básicos del diseño sin utilizar una gran cantidad de plástico, además

reducir el tiempo de impresión de modelos.

Los errores encontrados a lo largo del proceso de producción más destacados

fueron los siguientes:

- La dificultad para retirar algunos tipos de carcasas, especialmente de materiales

metálicos puede provocar que en algún momento los componentes internos

puedan ser dañados, como sucedió con el adaptador HDMI.

- El proceso de diseño e impresión de las carcasas, en concreto los modelos finales

requerían de mucho tiempo de impresión, ya que se imprimían en alta resolución,

obteniendo mejores acabados. Esto producía que modelos con defectos

milimétricos quedasen inservibles.

- La dificultad para retirar el aislante de los cables, estos cables eran tan finos que,

al utilizar herramientas para retirar el aislante de los cables acabaran

rompiéndose, dificultando un proceso que podría haber sido más sencillo.

- Problemas varios con la impresora 3D, que ocurrieron a lo largo de todo el proceso

de impresión. Eran errores de funcionamiento de la impresora, que provocó que

perdiésemos gran cantidad de tiempo que no estaba previsto solventando estos

problemas.

- La especificación del estándar USB-C, que limita en gran medida las

modificaciones con la amplia lista de protecciones contra sobrecargas.

Teniendo en cuenta los errores encontrados a lo largo del procedimiento, si

diseñáramos una placa base desde cero teniendo en cuenta los requisitos del estándar

podrían fabricarse modelos más compactos, eficientes y con un menor gasto de

recursos. Incluso se podrían diseñar teniendo en cuenta el factor de la reparabilidad y

diseñarlo de forma que los módulos puedan ser reemplazados fácilmente por personas

con poca experiencia con la electrónica. Esto se podría implementar mediante un sistema

de pines en las dos placas, que se inserte una dentro de otra. En consecuencia,

solamente haría falta conectar los módulos para conseguir un adaptador funcional.

Figura 61: Nueva propuesta de diseño (conexión). | Figura 62: Nueva propuesta de diseño (conexión).

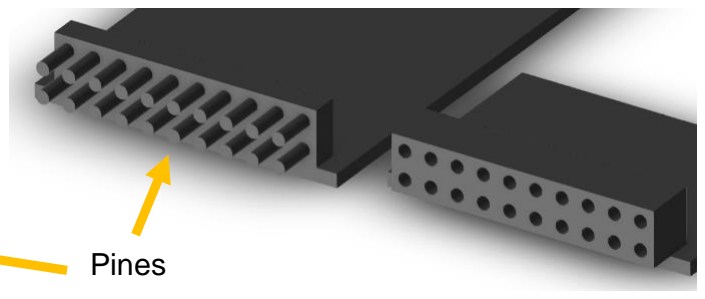
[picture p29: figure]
Pines
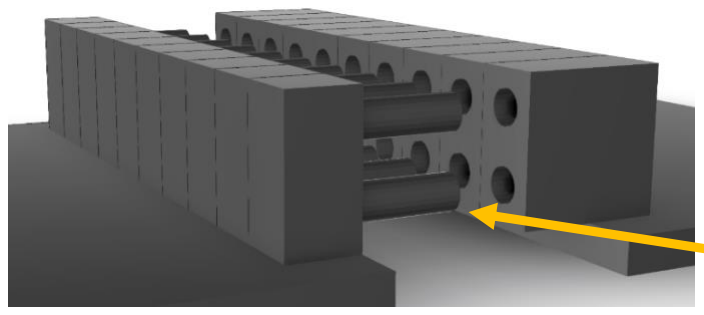
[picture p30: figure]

Fuente: Elaboración propia. | Fuente: Elaboración propia.

Algunas mejoras que se podrían aplicar al diseño de las carcasas serían las

siguientes:

- Modificar ligeramente el sistema de cierre para hacerlo simétrico, pudiendo así

colocar el cuerpo dentro de la tapa de cualquier manera.

- Idear otras formas de impresión del modelo, evitando que la trama del plástico

haga ruido al introducir el cuerpo dentro de la tapa.

Para ello, habría que imprimirlo en horizontal,

encontrando una manera en la que se pueda evitar

que las zonas curvas se impriman desigualmente.

- Optimizar el diseño, reduciendo la cantidad de

filamento y de tiempo de impresión. Esto se podría

realizar diseñando soportes para las placas base en

diagonal (para que soporte más fuerza y utilice

menos filamento) y rebajando la altura de estos

soportes, ya que el grosor de la placa no requiere

de tanta altura.

Figura 63: Nueva propuesta de

diseño (cuerpo).

Fuente: Elaboración propia.

### 5. BIBLIOGRAFÍA

All USB. (s.f.). USB History. Recuperado el 07 de enero de 2019, de http://www.allusb.com/usb-history

Apple Inc. (s.f.). Adaptador de USB-C a Gigabit Ethernet de Belkin. Recuperado el 13 de diciembre de 2018, de https://www.apple.com/es/shop/product/HJKF2ZM/A/adaptador-de-usb-c-a-gigabit-ethernet-de-belkin

Apple Inc. (s.f.). Adaptador de USB-C a lector de tarjetas SD. Recuperado el 13 de diciembre de 2018, de https://www.apple.com/es/shop/product/MUFG2ZM/A/adaptador-de-usb-c-a-lector-de-tarjetas-sd

Apple Inc. (s.f.). Adaptador de USB-C a USB. Recuperado el 13 de diciembre de 2018, de https://www.apple.com/es/shop/product/MJ1M2ZM/A/adaptador-de-usb-c-a-usb

Apple Inc. (s.f.). Adaptador multipuerto de USB-C a AV digital. Recuperado el 13 de diciembre de 2018, de https://www.apple.com/es/shop/product/MJ1K2ZM/A/adaptador-multipuerto-de-usb-c-a-av-digital

STMicroelectronics. (2016). USB Power Delivery and Type-C. Recuperado el 08 de enero de 2018, de
https://www.st.com/content/ccc/resource/sales_and_marketing/presentation/product_presentation/group0/5a/b1/8e/6c/2b/0d/46/3c/Apec/files/APEC_2016_USB_Power.pdf/_jcr_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

USB Implementers Forum. (2016). USB Type-C Overview. Developer Days 2016. Hong Kong. Recuperado el 23 de octubre de 2018, de https://web.archive.org/web/20161220102924/http://www.usb.org/developers/presentations/USB_DevDays_Hong_Kong_2016_-_USB_Type-C.pdf

USB Implementers Forum. (14 de julio de 2017). Universal Serial Bus Type-C Cable and Connector Specification. Recuperado el 11 de enero de 2019, de https://www.usb.org/sites/default/files/USB%20Type-C_20181031.zip

Wikipedia, La enciclopedia libre. (11 de mayo de 2018). Acido poliláctico. Recuperado el 13 de diciembre de 2018, de
https://es.wikipedia.org/w/index.php?title=%C3%81cido_polil%C3%A1ctico&oldid=1077 06392

Wikipedia, La enciclopedia libre. (5 de diciembre de 2018). USB-C. Recuperado el 13 de diciembre de 2018, de https://es.wikipedia.org/w/index.php?title=USB-C&oldid=112467186

Wikipedia, The Free Encyclopedia. (12 de diciembre de 2018). USB-C. Recuperado el 13 de diciembre de 2018, de https://en.wikipedia.org/w/index.php?title=USB-C&oldid=873294970

Wikipedia, The Free Encyclopedia. (6 de enero de 2019). USB. Recuperado el 7 de enero de 2019, de https://en.wikipedia.org/w/index.php?title=USB&oldid=877034284

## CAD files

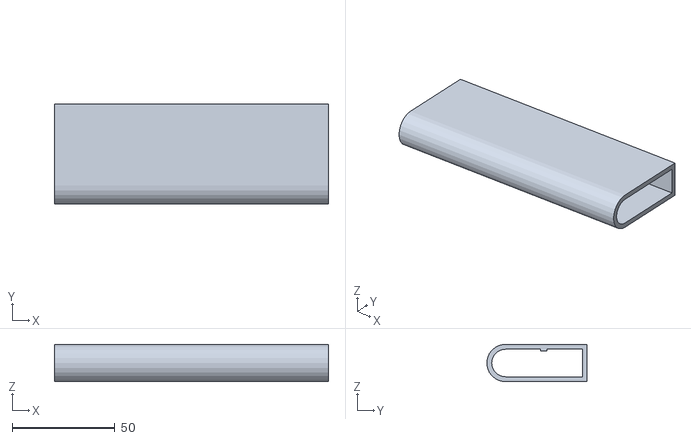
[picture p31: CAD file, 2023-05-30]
stl/usb_case_1.4.stl
133.4 x 48.9 x 18.2

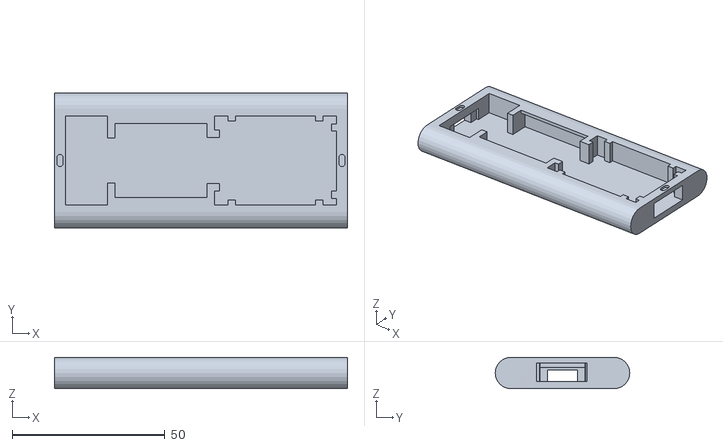
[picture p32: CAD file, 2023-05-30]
stl/hdmi_body_1.3.stl
96.0 x 44.1 x 10.3

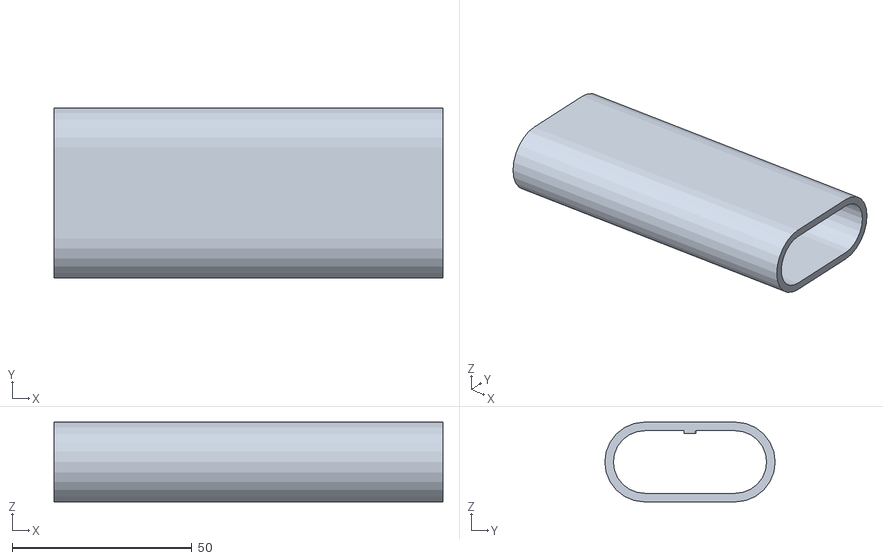
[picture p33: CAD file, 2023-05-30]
stl/ethernet_case_1.4.stl
108.2 x 47.4 x 22.2

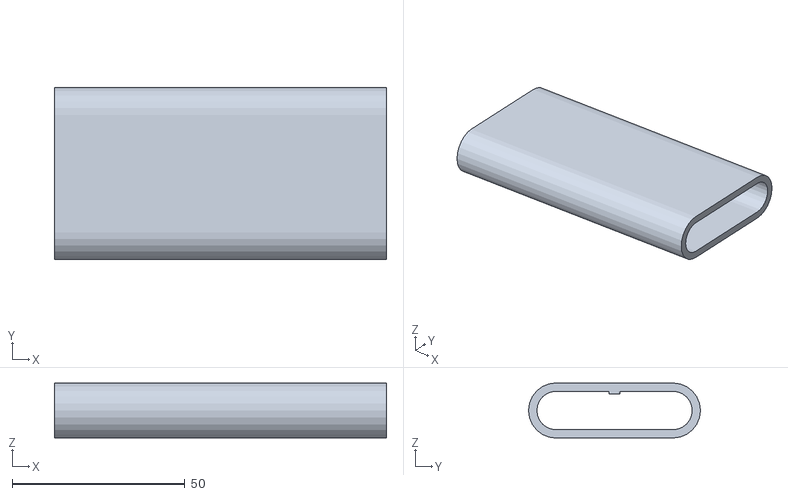
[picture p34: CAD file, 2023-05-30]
stl/hdmi_case_1.3.stl
96.0 x 49.7 x 15.9

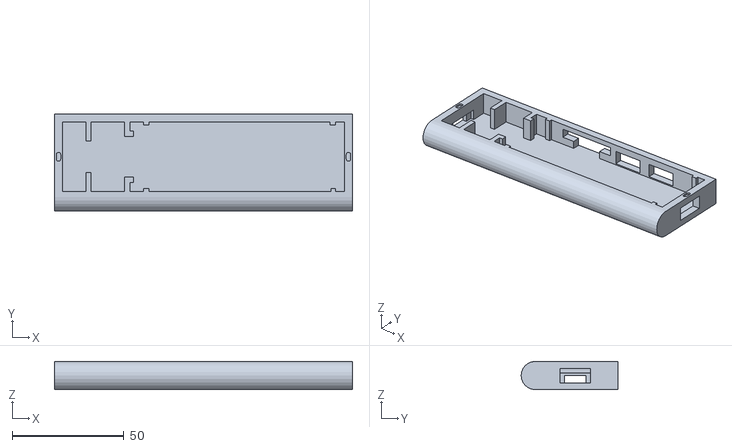
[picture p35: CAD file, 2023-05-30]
stl/usb_body_1.4.stl
133.4 x 43.3 x 12.6

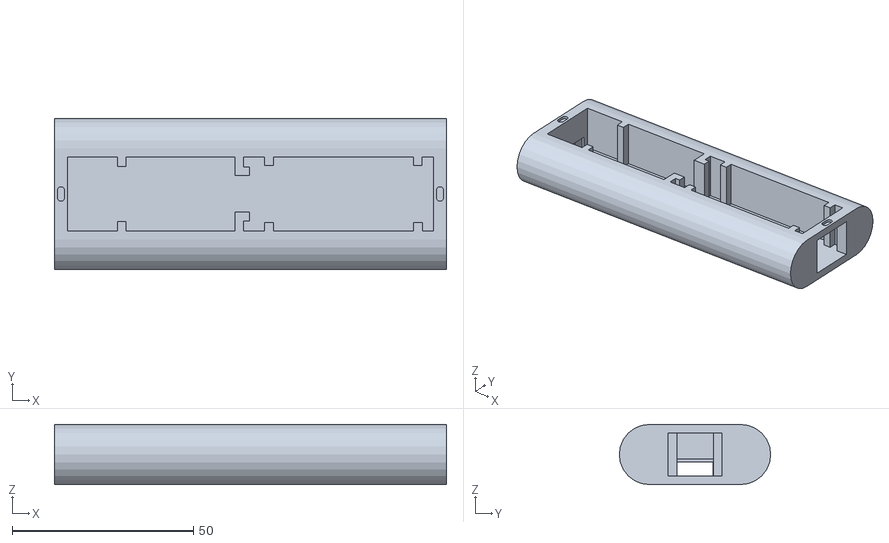
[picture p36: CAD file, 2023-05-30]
stl/ethernet_body_1.4.stl
108.2 x 41.8 x 16.6
